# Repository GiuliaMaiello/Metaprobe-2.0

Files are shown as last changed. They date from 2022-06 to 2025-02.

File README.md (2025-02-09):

# Metaprobe-2.1
The Metaprobe: a nimble, low-cost environmental DNA sampler for upscaling acquatic monitoring 

Bezombes F., Maiello G., Mariani S., Neave E., Russo T., Shum P.

The project2.1 folder contains a new 3D project to print a 2.1 version of the metaprobe, in the same original design and with a reduction of the discard plastic material.
We thank Thomas Byrne for this updated project.

If you are still interested in the older 2.0 design, you can request it directly from the authors.

This repository contains all the instruction you need to prepare and use the Metaprobe, a hollow perforated spherical probe that when filled with rolls of gauze is used as a low-cost and low-effort eDNA sampler in acquatic environments. 
In the **project** folder you can find all the files to 3D print your own Metaprobes. In the **tutorial** folder there are protocols explaining how to prepare and use a Metaprobe with the rolls of gauze.

Here is the link to a YouTube video showing everything you need to do to use a Metaprobe: https://player.vimeo.com/video/744958355?h=4112059eef

Note that this is a CC-BY-NC-ND project.

If you want to know more: https://www.sciencedirect.com/science/article/pii/S0165783622000364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

For any question please contact <span style="color: blue;">g.maiello@ljmu.ac.uk</span>, <span style="color: blue;">f.bezombes@ljmu.ac.uk</span>, <span style="color: blue;">e.f.neave@ljmu.ac.uk</span> 

How to cite: Maiello, G., Talarico, L., Carpentieri, P., De Angelis, F., Franceschini, S., Harper, L. R., Neave, E.F., Rickards, O., Sbrana, A., Shum, P., Veltre, V., Mariani, S., Russo, T. (2022). Little samplers, big fleet: eDNA metabarcoding from commercial trawlers enhances ocean monitoring. Fisheries Research, 249, 106259.

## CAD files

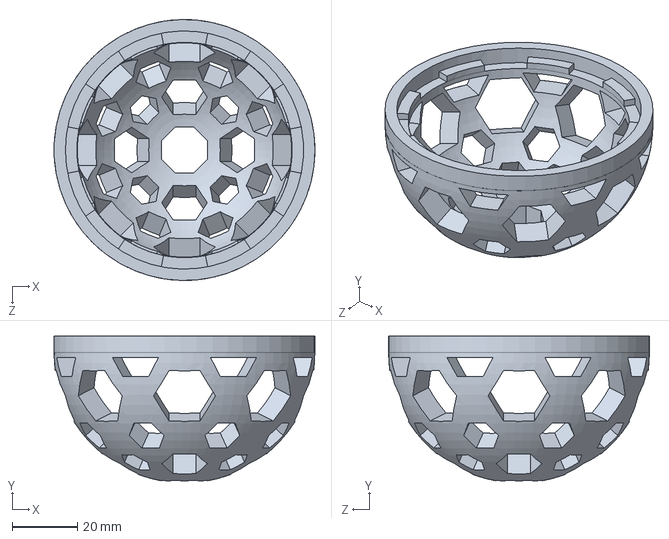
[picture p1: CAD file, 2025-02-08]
project2.1/BASIC for print top.SLDPRT
80.0 x 44.4 x 80.0 mm

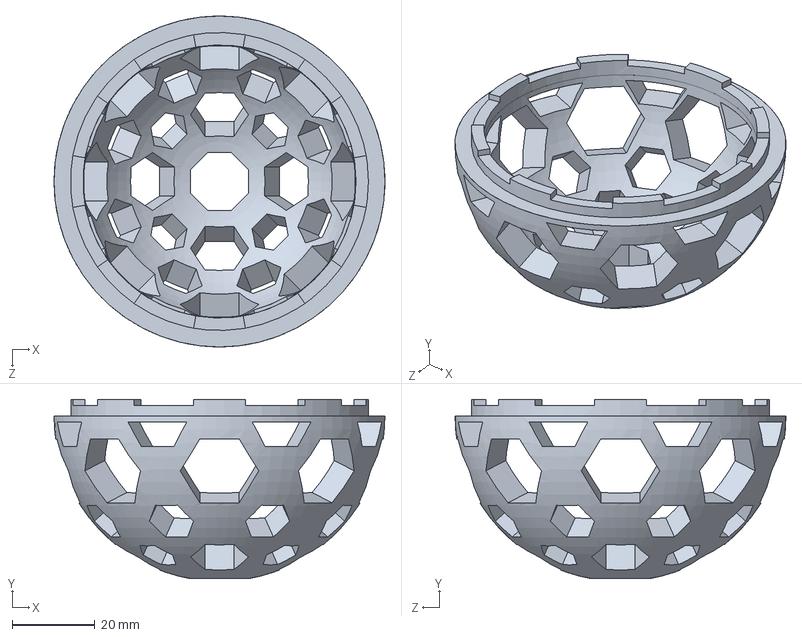
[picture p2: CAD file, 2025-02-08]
project2.1/BASIC for print bottom.SLDPRT
80.0 x 43.4 x 80.0 mm

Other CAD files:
project2.1/BASIC for print bottom.STL
project2.1/BASIC for print top.STL

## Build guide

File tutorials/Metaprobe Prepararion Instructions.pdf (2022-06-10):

## METAPROBE PREPARATION INSTRUCTIONS

Materials needed:

- Medical gloves
- Metaprobe
- Scissors
- Bleach
- Distilled water
- Lipsol or a similar cleaning detergent
- Zip-ties
- Sterile medical gauze

Cleaning the Metaprobe:

1. Wear medical gloves for the entire procedure
2. Rinse the dirty metaprobes with water, removing any residue.
3. In a clean basin prepare a 10% bleach solution to clean metaprobes and scissors.
4. Soak the dirty metaprobes and scissors in the
bleach solution for at least half an hour.
5. In another clean basin prepare a 5% lipsoil (or another cleaning detergent) solution to rinse the metaprobes and scissors
6. Transfer the bleached metaprobes and scissors to the lipsol bath for 5 min. Since bleach
degrades DNA, it is critical to remove excess
bleach before preparing clean metaprobes.

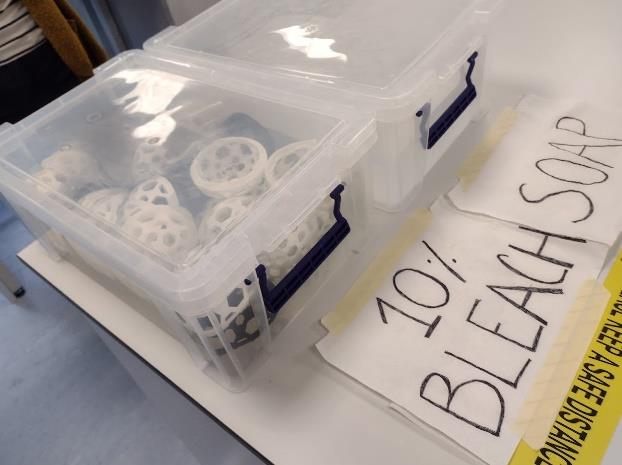
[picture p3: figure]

7. Allow the scissors and metaprobe to air dry on paper towels or a clean surface.

Building the Metaprobe:

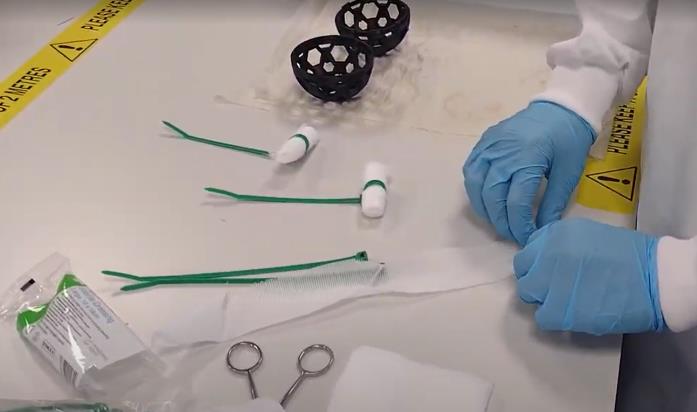
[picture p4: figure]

1. | Prepare | three | rolls | of | medical
dressings, per each metaprobe.

Clean a surface with 10% bleach. Open a sterile medical dressing and unroll it. With clean scissors cut the cotton and gauze as needed so that the gauze wraps around the cotton inside, forming a roll similar in size to a sterivex filter (i.e. 5-6 cm length, 1-2 cm diameter). Loosely, secure the roll with a zip-tie. Trim the tail of the zip-tie. This step is more of an art than a science. Each roll will look slightly different: this is not going to affect the results!

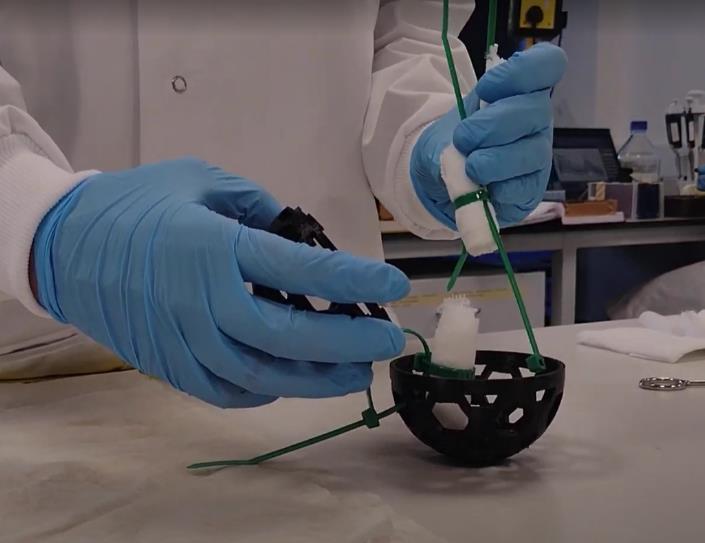
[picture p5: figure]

### 2. Secure medical dressing rolls in the

metaprobes.

Three rolls of gauze (step 1) will be placed in each metaprobe. Slide another zip-tie through the loose zip-tie loop, so that it is parallel to the medical dressing roll. Place the roll into the metaprobe and feed either end of the parallel zip-tie into opposite halves of the metaprobe. Clasp this zip-tie together (connecting both halves of the metaprobe) keeping the loop large. Repeat twice more, so that three rolls are in the metaprobe. Tighten down all three zip-ties,
as you close the metaprobe.

### 3. Keep the metaprobes in a clean

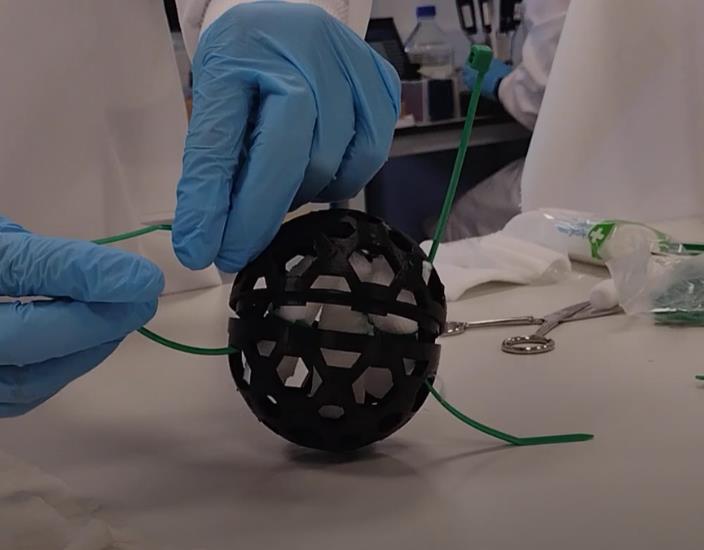
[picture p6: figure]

storage place until you use it. (e.g. a clean zip-lock bag).

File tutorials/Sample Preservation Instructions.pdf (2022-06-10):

## SAMPLE COLLECTION AND PRESERVATION INSTRUCTIONS

Materials needed:

- Medical gloves
- Clean scissors
- Bleach
- 50ml sterile tubes

Collect and store samples from a metaprobe:

1. Wear medical gloves
2. Collect the metaprobe from wherever you are using it
3. Open the metaprobe on a clean surface.
Clean a surface with 10% bleach (if possible) or a cleaning product that contains bleach. Cut the zip-ties that hold the metaprobe closed.

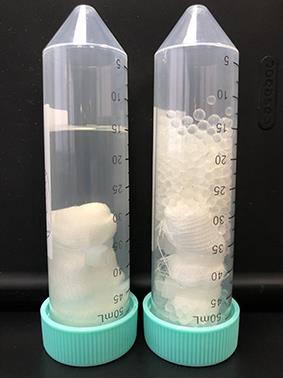
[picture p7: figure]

4. Place each roll of gauze into a 50ml sterile tube.
Fill the 50ml sterile tube with either silica beads or 99% ethanol
to preserve the genetic material. If silica beads, ensure the beads totally surround the roll of gauze. If using 99% ethanol, make sure the sample is completely submerged.
5. Keep the samples in a cool, safe place.
In the field, keep the sample tubes in a place as cold and safe as possible. Once in the lab, the samples should be frozen at -20°C until DNA extraction.
